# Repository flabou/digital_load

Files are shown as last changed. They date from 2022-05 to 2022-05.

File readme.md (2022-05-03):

# Digital load
This is a digital load circuit, project is WIP.
Intended features are:
- USB type-C connector with USB-2.0 supply (5V 500mA)
- Oled display to show current setting (and maybe other stuff)
- Encoder wheel with push-button to change current value
- Ability to connect several circuit (only one with screen, encoder, and usb supply) which will communicate through I2C and share the load (to reach higher current load)
- Several sense resistors to increase dynamic range.
- Maximum current and voltage are to be determined, current will probably be on the order of 1 to 5 amps max, ~1uA min
- USB serial interface, maybe to control from computer and read measured current points, this would allow to specify curve for the load for instance, if there's a use for it.

# Screenshots

Render of the board (top)

Render of the board (perspective)

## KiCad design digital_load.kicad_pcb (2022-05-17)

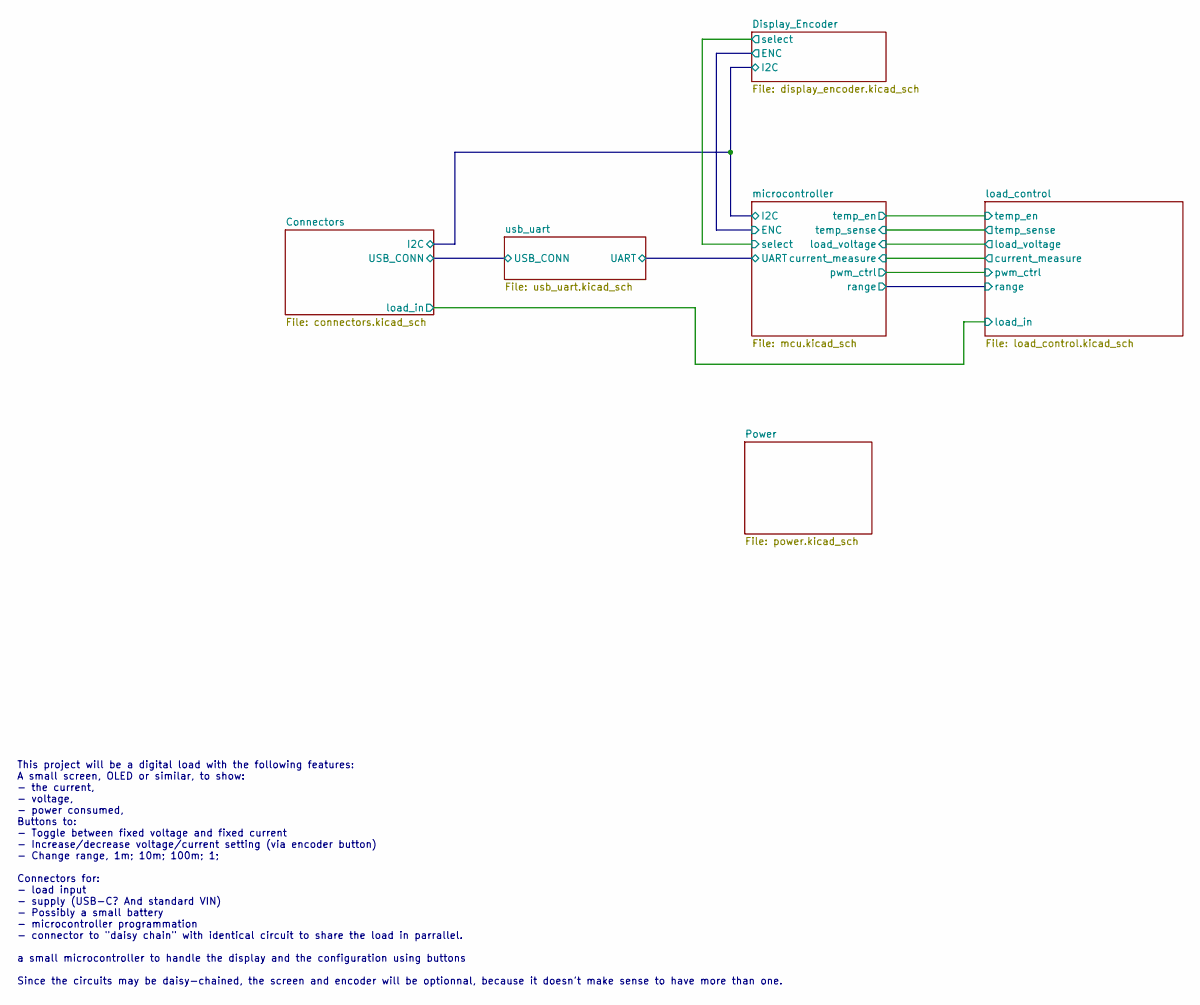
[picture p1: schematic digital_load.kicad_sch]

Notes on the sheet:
This project will be a digital load with the following features: A small screen, OLED or similar, to show: - the current, - voltage, - power consumed, Buttons to: - Toggle between fixed voltage and fixed current - Increase/decrease voltage/current setting (via encoder button) - Change range, 1m; 10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

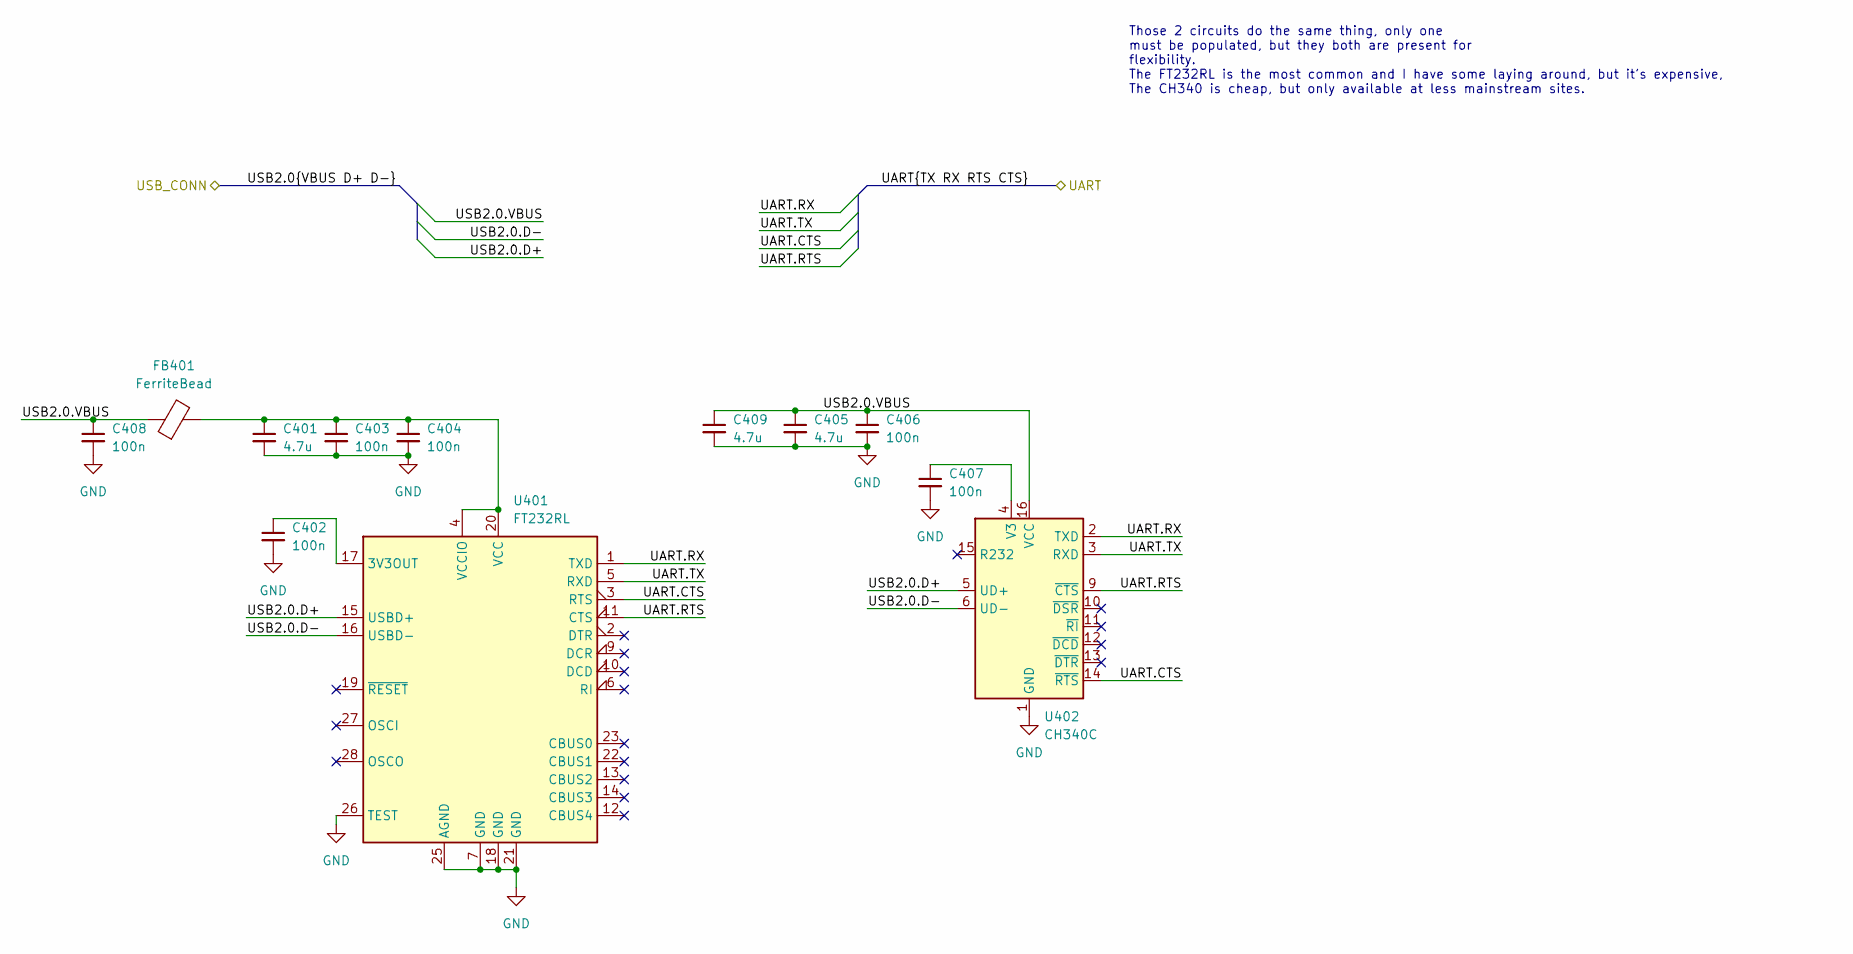
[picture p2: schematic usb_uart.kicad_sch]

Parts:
C401, C405, C409: 4.7u; C_0805_2012Metric; PartNumber Generic
C402, C403, C404, C406, C407, C408: 100n; C_0402_1005Metric; PartNumber Generic
FB401: FerriteBead; L_0805_2012Metric; PartNumber MH2029-400Y
U401: FT232RL; SSOP-28_5.3x10.2mm_P0.65mm; PartNumber FT232RL
U402: CH340C; SOIC-16_3.9x9.9mm_P1.27mm; PartNumber CH340C

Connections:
+5V: C405.1, C406.1, C408.1, C409.1, FB401.1, U402.16 (VCC); also elsewhere on the board
/Connectors/USB2.0.D+: U401.15 (USBD+), U402.5 (UD+); also elsewhere on the board
/Connectors/USB2.0.D-: U401.16 (USBD-), U402.6 (UD-); also elsewhere on the board
/microcontroller/UART.CTS: U401.3 (RTS), U402.14 (~RTS); also elsewhere on the board
/microcontroller/UART.RTS: U401.11 (CTS), U402.9 (~CTS); also elsewhere on the board
/microcontroller/UART.RX: U401.1 (TXD), U402.2 (TXD); also elsewhere on the board
/microcontroller/UART.TX: U401.5 (RXD), U402.3 (RXD); also elsewhere on the board
GND: C401.2, C402.2, C403.2, C404.2, C405.2, C406.2, C407.2, C408.2, C409.2, U401.7 (GND), U401.18 (GND), U401.21 (GND), U401.25 (AGND), U401.26 (TEST), U402.1 (GND); also elsewhere on the board
unnamed: C401.1, C403.1, C404.1, FB401.2, U401.4 (VCCIO), U401.20 (VCC)
unnamed: C402.1, U401.17 (3V3OUT)
unnamed: C407.1, U402.4 (V3)

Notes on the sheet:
Those 2 circuits do the same thing, only one must be populated, but they both are present for flexibility. The FT232RL is the most common and I have some laying around, but it's expensive, The CH340 is cheap, but only available at less mainstream sites.

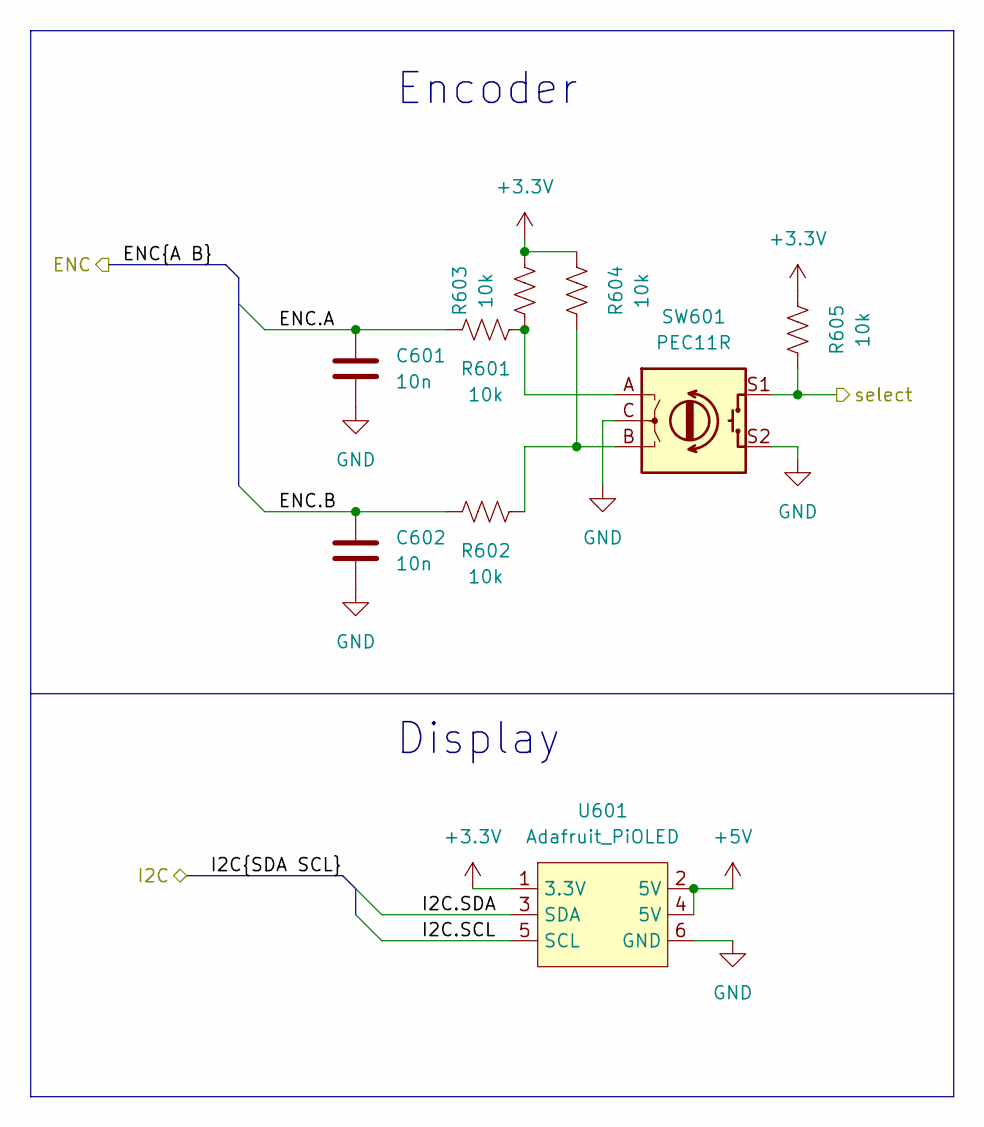
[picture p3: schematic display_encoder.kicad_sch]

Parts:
C601, C602: 10n; C_0805_2012Metric; PartNumber Generic
R601, R602, R603, R604, R605: 10k; R_0805_2012Metric; PartNumber Generic
SW601: PEC11R; RotaryEncoder_Alps_EC12E-Switch_Vertical_H20mm; PartNumber PEC11R-4215F-S0024
U601: Adafruit_PiOLED; PiOLED; PartNumber PiOled

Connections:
+3V3: R603.1, R604.2, R605.2, U601.1 (3.3V); also elsewhere on the board
+5V: U601.2 (5V), U601.4 (5V); also elsewhere on the board
/Connectors/I2C.SCL: U601.5 (SCL); also elsewhere on the board
/Connectors/I2C.SDA: U601.3 (SDA); also elsewhere on the board
/Display_Encoder/ENC.A: C601.2, R601.1; also elsewhere on the board
/Display_Encoder/ENC.B: C602.2, R602.1; also elsewhere on the board
/Display_Encoder/select: R605.1, SW601.S1; also elsewhere on the board
GND: C601.1, C602.1, SW601.C, SW601.S2, U601.6 (GND); also elsewhere on the board
unnamed: R601.2, R603.2, SW601.A
unnamed: R602.2, R604.1, SW601.B

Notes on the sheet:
Encoder
Display

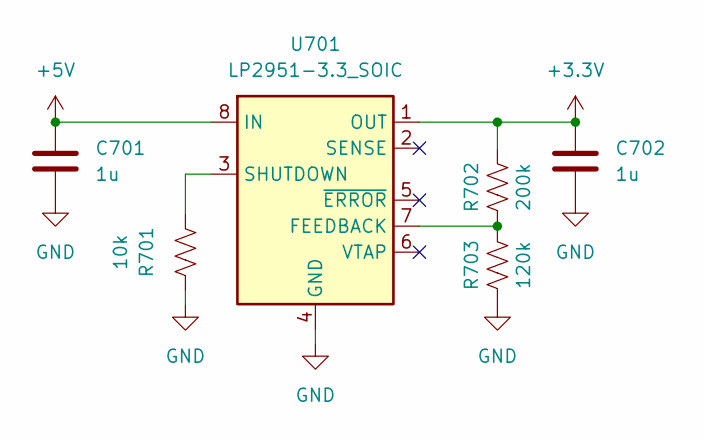
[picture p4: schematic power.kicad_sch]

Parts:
C701, C702: 1u; C_0805_2012Metric; PartNumber Generic
R701: 10k; R_0805_2012Metric; PartNumber Generic
R702: 200k; R_0805_2012Metric; PartNumber Generic
R703: 120k; R_0805_2012Metric; PartNumber Generic
U701: LP2951-3.3_SOIC; SOIC-8_3.9x4.9mm_P1.27mm; PartNumber LP2951-30D

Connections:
+3V3: C702.1, R702.1, U701.1 (OUT); also elsewhere on the board
+5V: C701.1, U701.8 (IN); also elsewhere on the board
GND: C701.2, C702.2, R701.2, R703.2, U701.4 (GND); also elsewhere on the board
unnamed: R701.1, U701.3 (SHUTDOWN)
unnamed: R702.2, R703.1, U701.7 (FEEDBACK)

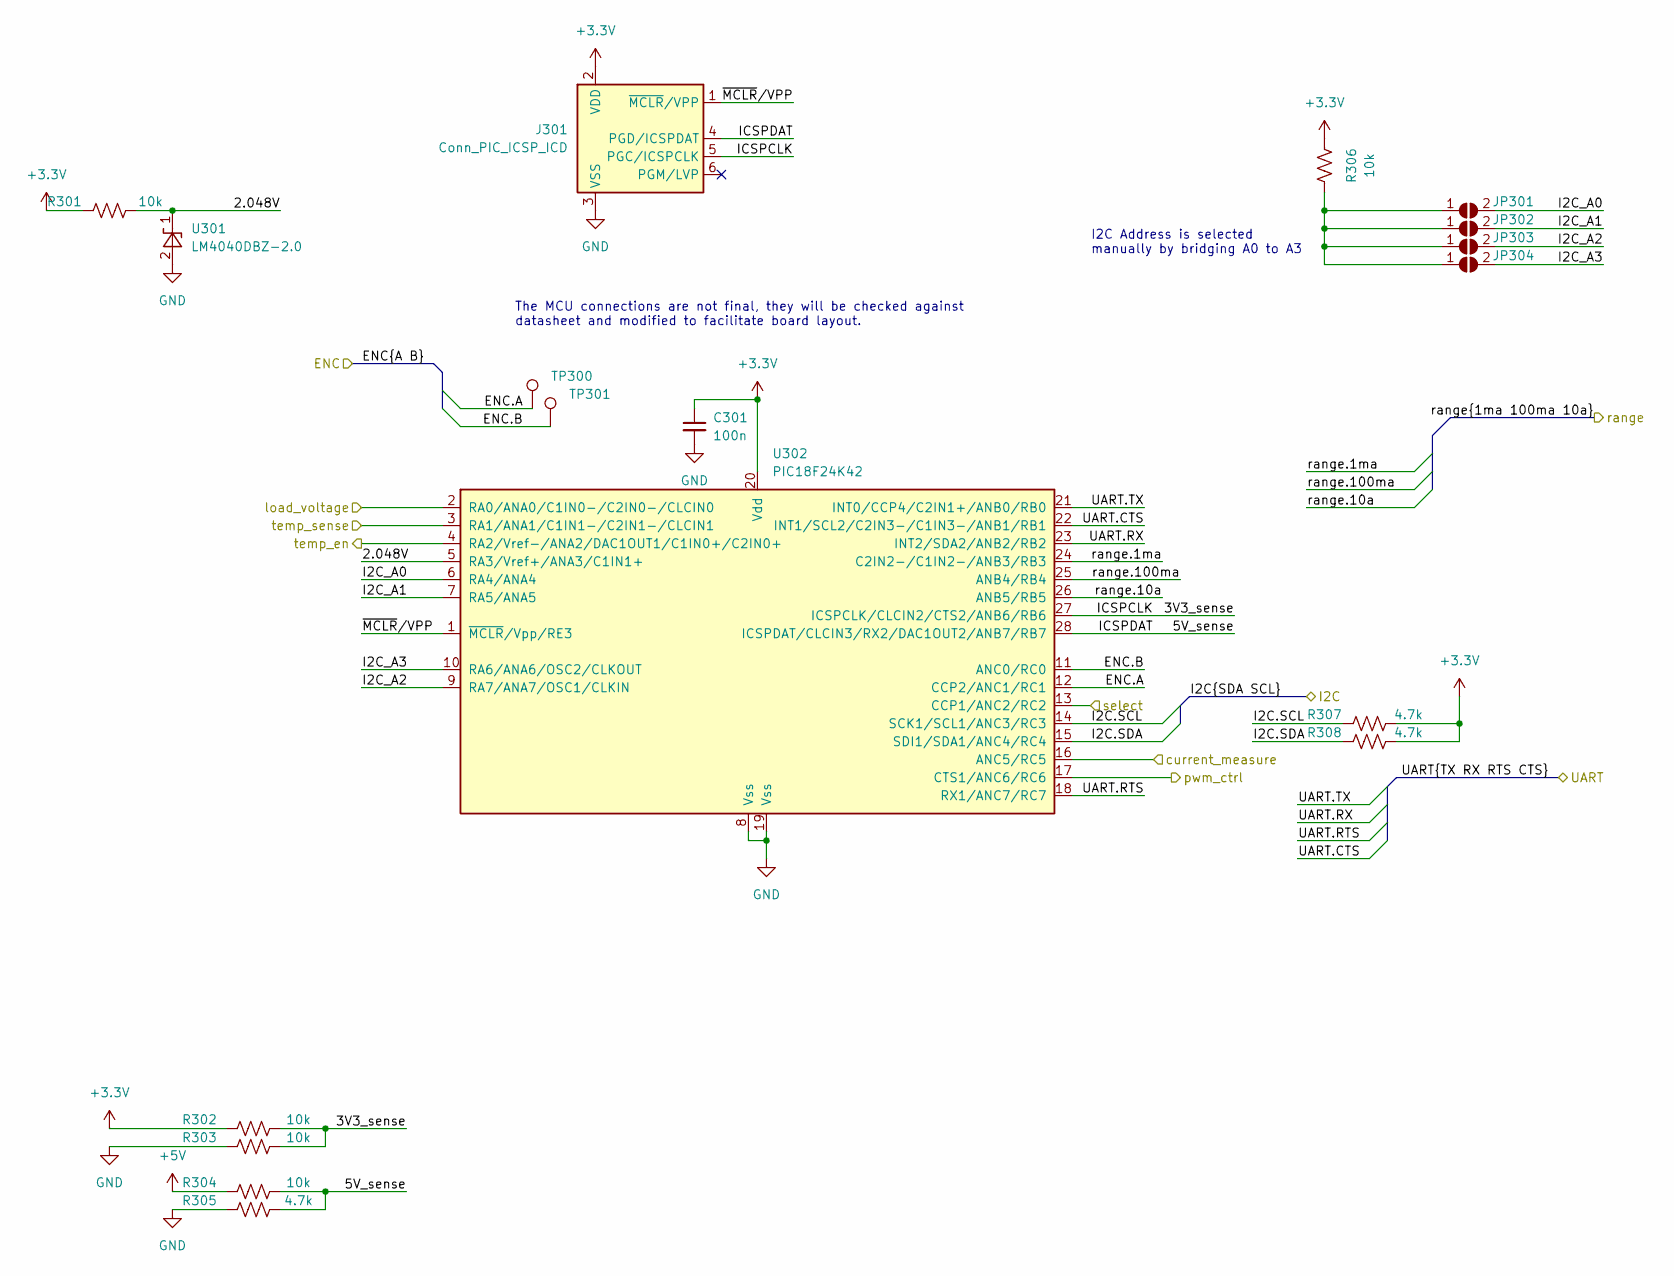
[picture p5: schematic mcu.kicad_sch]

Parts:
C301: 100n; C_0402_1005Metric; PartNumber Generic
J301: Conn_PIC_ICSP_ICD; PinHeader_1x06_P2.54mm_Vertical; PartNumber Generic
JP301, JP302, JP303, JP304: SB; SolderJumper-2_P1.3mm_Open_TrianglePad1.0x1.5mm; PartNumber N.A.
R301, R302, R303, R304, R306: 10k; R_0805_2012Metric; PartNumber Generic
R305, R307, R308: 4.7k; R_0805_2012Metric; PartNumber Generic
TP300, TP301: TestPoint_Pad_D1.0mm; PartNumber N.A.
U301: LM4040DBZ-2.0; SOT-23; PartNumber LM4040C20QDBZT
U302: PIC18F24K42; SSOP-28_5.3x10.2mm_P0.65mm; PartNumber PIC18F24K42

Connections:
+3V3: C301.1, J301.2 (VDD), R301.2, R302.2, R306.2, R307.1, R308.1, U302.20 (Vdd); also elsewhere on the board
+5V: R304.2; also elsewhere on the board
/Connectors/I2C.SCL: R307.2, U302.14 (SCK1/SCL1/ANC3/RC3); also elsewhere on the board
/Connectors/I2C.SDA: R308.2, U302.15 (SDI1/SDA1/ANC4/RC4); also elsewhere on the board
/Display_Encoder/ENC.A: TP300.1, U302.12 (CCP2/ANC1/RC1); also elsewhere on the board
/Display_Encoder/ENC.B: TP301.1, U302.11 (ANC0/RC0); also elsewhere on the board
/Display_Encoder/select: U302.13 (CCP1/ANC2/RC2); also elsewhere on the board
/load_control/current_measure: U302.16 (ANC5/RC5); also elsewhere on the board
/load_control/load_voltage: U302.2 (RA0/ANA0/C1IN0-/C2IN0-/CLCIN0); also elsewhere on the board
/load_control/pwm_ctrl: U302.17 (CTS1/ANC6/RC6); also elsewhere on the board
/load_control/range.1ma: U302.24 (C2IN2-/C1IN2-/ANB3/RB3); also elsewhere on the board
/load_control/range.10a: U302.26 (ANB5/RB5); also elsewhere on the board
/load_control/range.100ma: U302.25 (ANB4/RB4); also elsewhere on the board
/load_control/temp_en: U302.4 (RA2/Vref-/ANA2/DAC1OUT1/C1IN0+/C2IN0+); also elsewhere on the board
/load_control/temp_sense: U302.3 (RA1/ANA1/C1IN1-/C2IN1-/CLCIN1); also elsewhere on the board
/microcontroller/2.048V: R301.1, U301.1 (K), U302.5 (RA3/Vref+/ANA3/C1IN1+)
/microcontroller/3V3_sense: J301.5 (PGC/ICSPCLK), R302.1, R303.2, U302.27 (ICSPCLK/CLCIN2/CTS2/ANB6/RB6)
/microcontroller/5V_sense: J301.4 (PGD/ICSPDAT), R304.1, R305.2, U302.28 (ICSPDAT/CLCIN3/RX2/DAC1OUT2/ANB7/RB7)
/microcontroller/I2C_A0: JP301.2 (B), U302.6 (RA4/ANA4)
/microcontroller/I2C_A1: JP302.2 (B), U302.7 (RA5/ANA5)
/microcontroller/I2C_A2: JP303.2 (B), U302.9 (RA7/ANA7/OSC1/CLKIN)
/microcontroller/I2C_A3: JP304.2 (B), U302.10 (RA6/ANA6/OSC2/CLKOUT)
/microcontroller/UART.CTS: U302.22 (INT1/SCL2/C2IN3-/C1IN3-/ANB1/RB1); also elsewhere on the board
/microcontroller/UART.RTS: U302.18 (RX1/ANC7/RC7); also elsewhere on the board
/microcontroller/UART.RX: U302.23 (INT2/SDA2/ANB2/RB2); also elsewhere on the board
/microcontroller/UART.TX: U302.21 (INT0/CCP4/C2IN1+/ANB0/RB0); also elsewhere on the board
/microcontroller/~MCLR/VPP: J301.1 (~MCLR/VPP), U302.1 (~MCLR/Vpp/RE3)
GND: C301.2, J301.3 (VSS), R303.1, R305.1, U301.2 (A), U302.8 (Vss), U302.19 (Vss); also elsewhere on the board
unnamed: JP301.1 (A), JP302.1 (A), JP303.1 (A), JP304.1 (A), R306.1

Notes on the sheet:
I2C Address is selected manually by bridging A0 to A3
The MCU connections are not final, they will be checked against datasheet and modified to facilitate board layout.

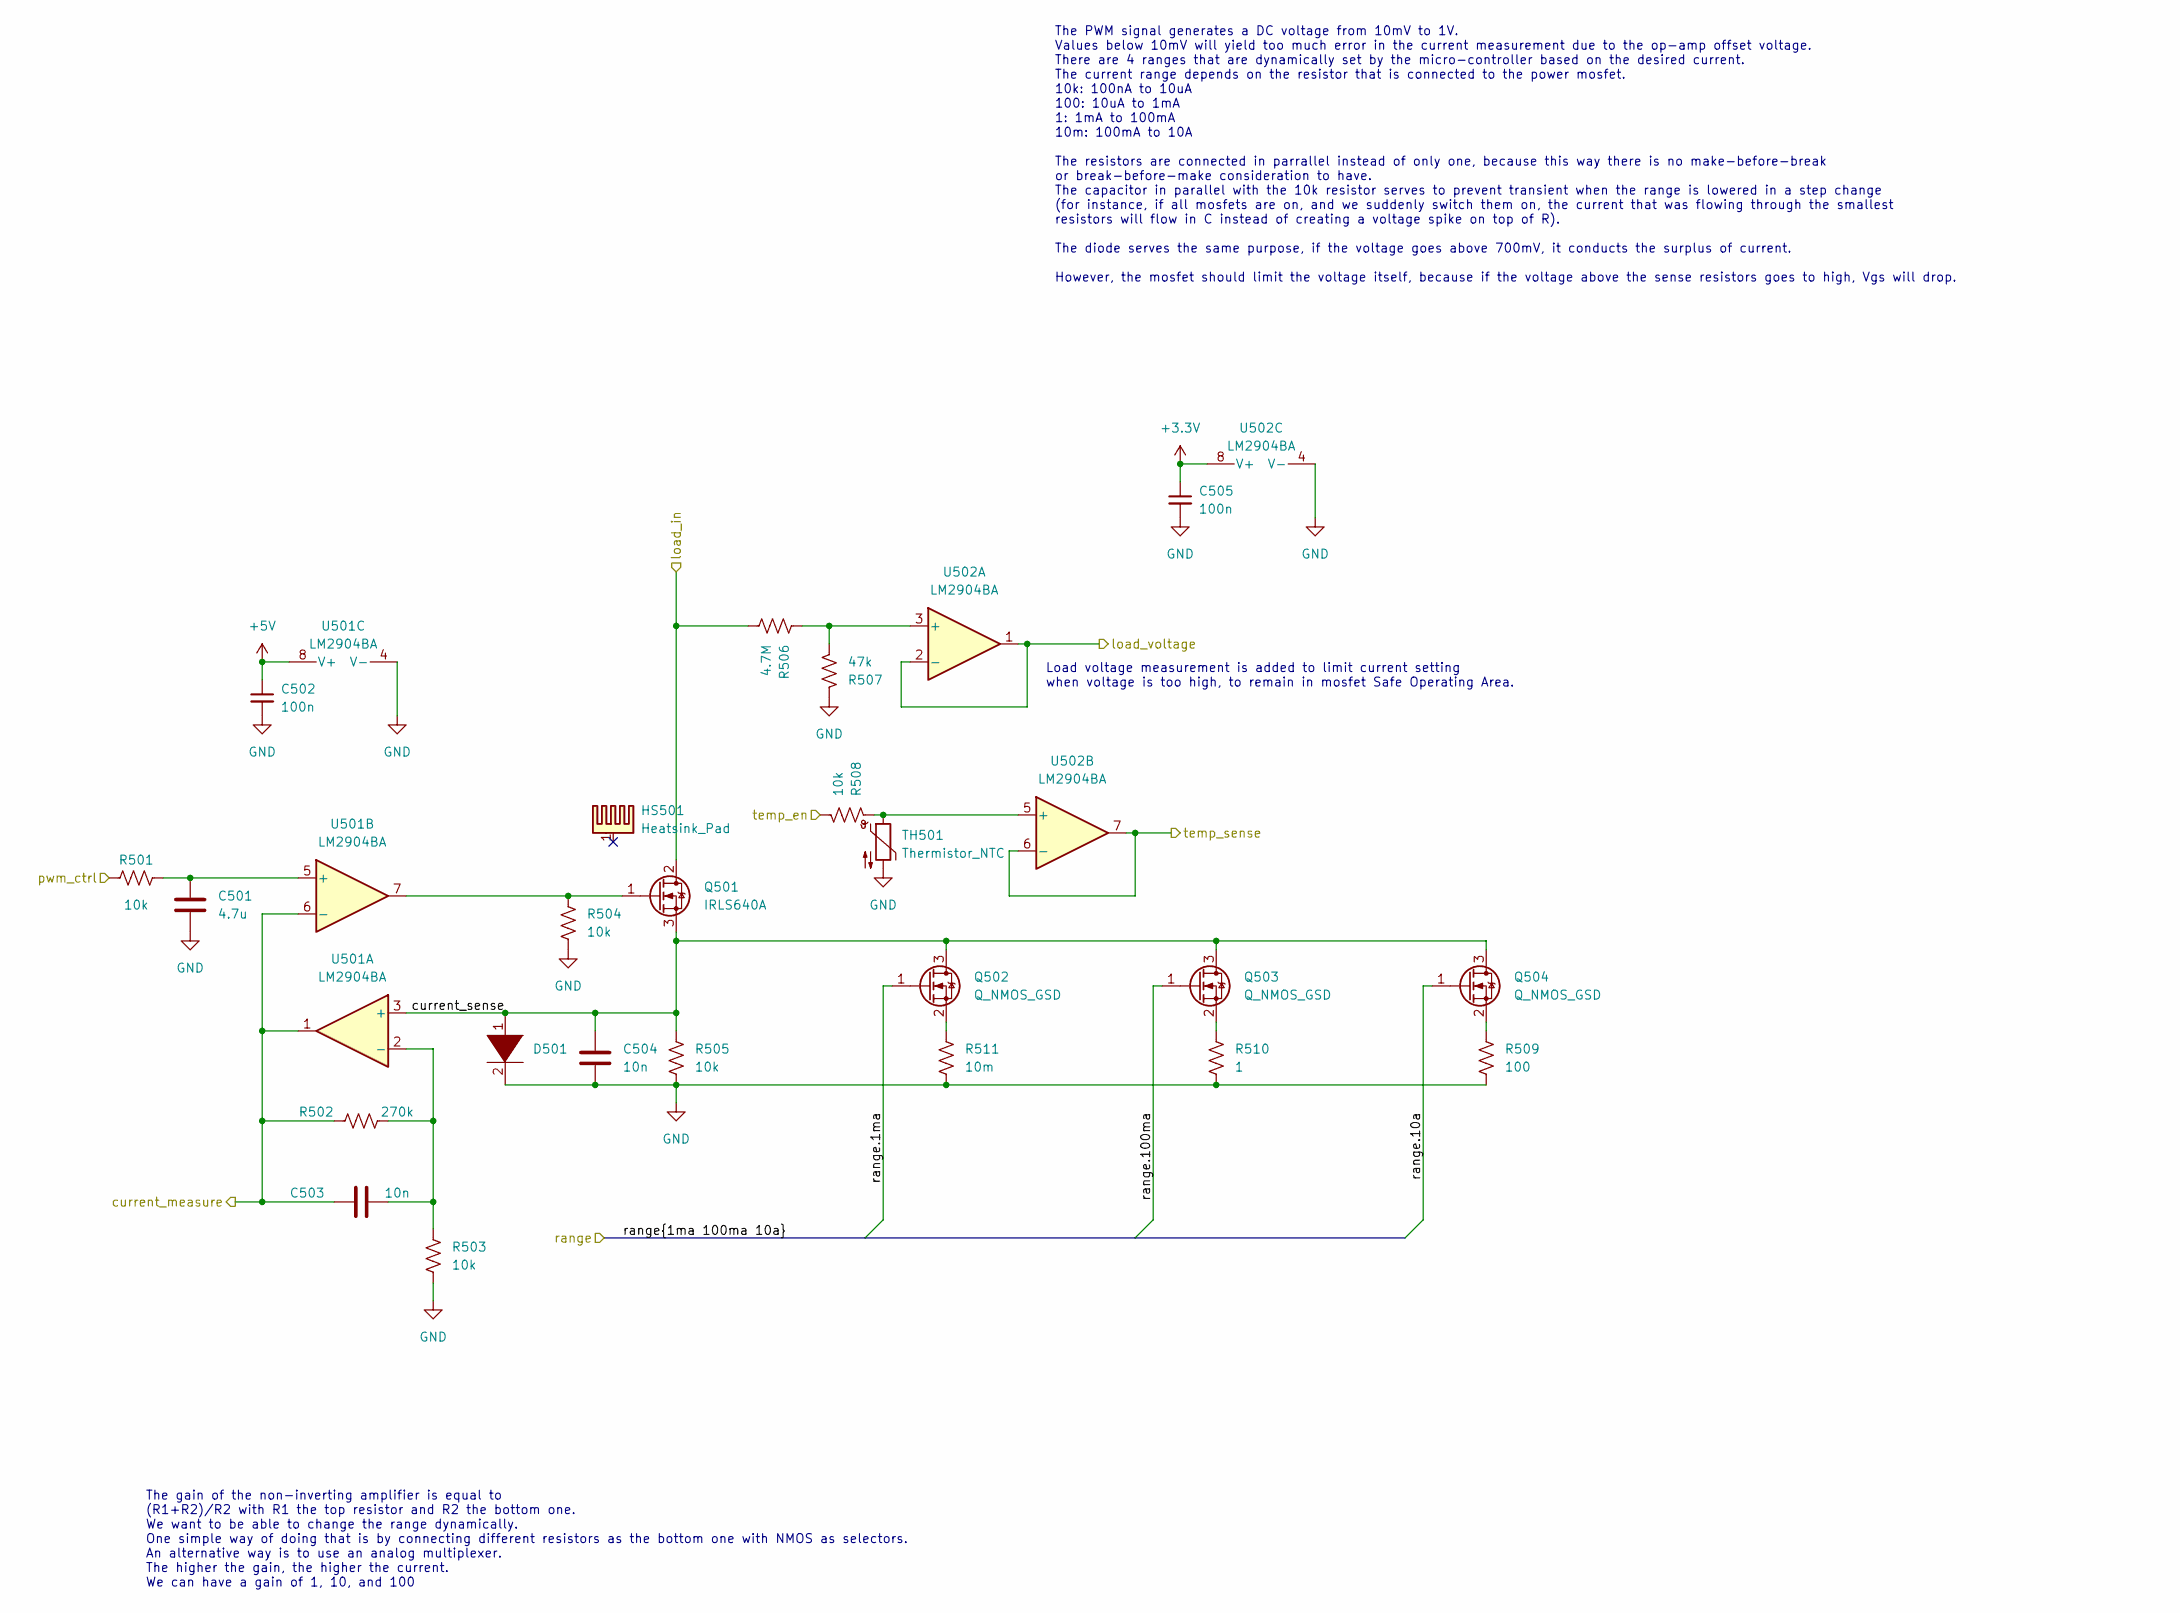
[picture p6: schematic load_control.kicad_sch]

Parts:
C501: 4.7u; C_0805_2012Metric; PartNumber Generic
C502, C505: 100n; C_0402_1005Metric; PartNumber Generic
C503, C504: 10n; C_0805_2012Metric; PartNumber Generic
D501: DIODE; D_SOD-323; PartNumber SD101AWS-TP
HS501: Heatsink_Pad; Heatsink_ASSMANN_WSW_V6560W; PartNumber V6560W
Q501: IRLS640A; TO-220-3_Vertical; PartNumber IRLS640A
Q502, Q503, Q504: Q_NMOS_GSD; SOT-23; PartNumber PJA3404_R1_00001
R501, R503, R504, R505, R508: 10k; R_0805_2012Metric; PartNumber Generic
R502: 270k; R_0805_2012Metric; PartNumber Generic
R506: 4.7M; R_0805_2012Metric; PartNumber Generic
R507: 47k; R_0805_2012Metric; PartNumber Generic
R509: 100; R_0805_2012Metric; PartNumber Generic
R510: 1; R_0805_2012Metric; PartNumber Generic
R511: 10m; R_0805_2012Metric; PartNumber Generic
TH501: Thermistor_NTC; R_0402_1005Metric; PartNumber NTCG103JF103FT1
U501, U502: LM2904BA; TSSOP-8_4.4x3mm_P0.65mm; PartNumber LM2904BAIPWR

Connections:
+3V3: C505.1, U502.8 (V+); also elsewhere on the board
+5V: C502.1, U501.8 (V+); also elsewhere on the board
/Connectors/load_in: Q501.2 (D), R506.1; also elsewhere on the board
/load_control/current_measure: C503.2, R502.2, U501.1, U501.6 (-); also elsewhere on the board
/load_control/current_sense: C504.2, D501.1 (K), Q501.3 (S), Q502.3 (D), Q503.3 (D), Q504.3 (D), R505.2, U501.3 (+)
/load_control/load_voltage: U502.1, U502.2 (-); also elsewhere on the board
/load_control/pwm_ctrl: R501.1; also elsewhere on the board
/load_control/range.1ma: Q502.1 (G); also elsewhere on the board
/load_control/range.10a: Q504.1 (G); also elsewhere on the board
/load_control/range.100ma: Q503.1 (G); also elsewhere on the board
/load_control/temp_en: R508.1; also elsewhere on the board
/load_control/temp_sense: U502.6 (-), U502.7; also elsewhere on the board
GND: C501.2, C502.2, C504.1, C505.2, D501.2 (A), R503.2, R504.1, R505.1, R507.2, R509.1, R510.1, R511.1, TH501.2, U501.4 (V-), U502.4 (V-); also elsewhere on the board
unnamed: C501.1, R501.2, U501.5 (+)
unnamed: C503.1, R502.1, R503.1, U501.2 (-)
unnamed: Q501.1 (G), R504.2, U501.7
unnamed: Q502.2 (S), R511.2
unnamed: Q503.2 (S), R510.2
unnamed: Q504.2 (S), R509.2
unnamed: R506.2, R507.1, U502.3 (+)
unnamed: R508.2, TH501.1, U502.5 (+)

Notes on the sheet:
Load voltage measurement is added to limit current setting when voltage is too high, to remain in mosfet Safe Operating Area.
The gain of the non-inverting amplifier is equal to (R1+R2)/R2 with R1 the top resistor and R2 the bottom one. We want to be able to change the range dynamically. One simple way of doing that is by connecting different resistors as the bottom one with NMOS as selectors. An alternative way is to use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
The PWM signal generates a DC voltage from 10mV to 1V. Values below 10mV will yield too much error in the current measurement due to the op-amp offset voltage. There are 4 ranges that are dynamically set by the micro-controller based on the desired current. The current range depends on the resistor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

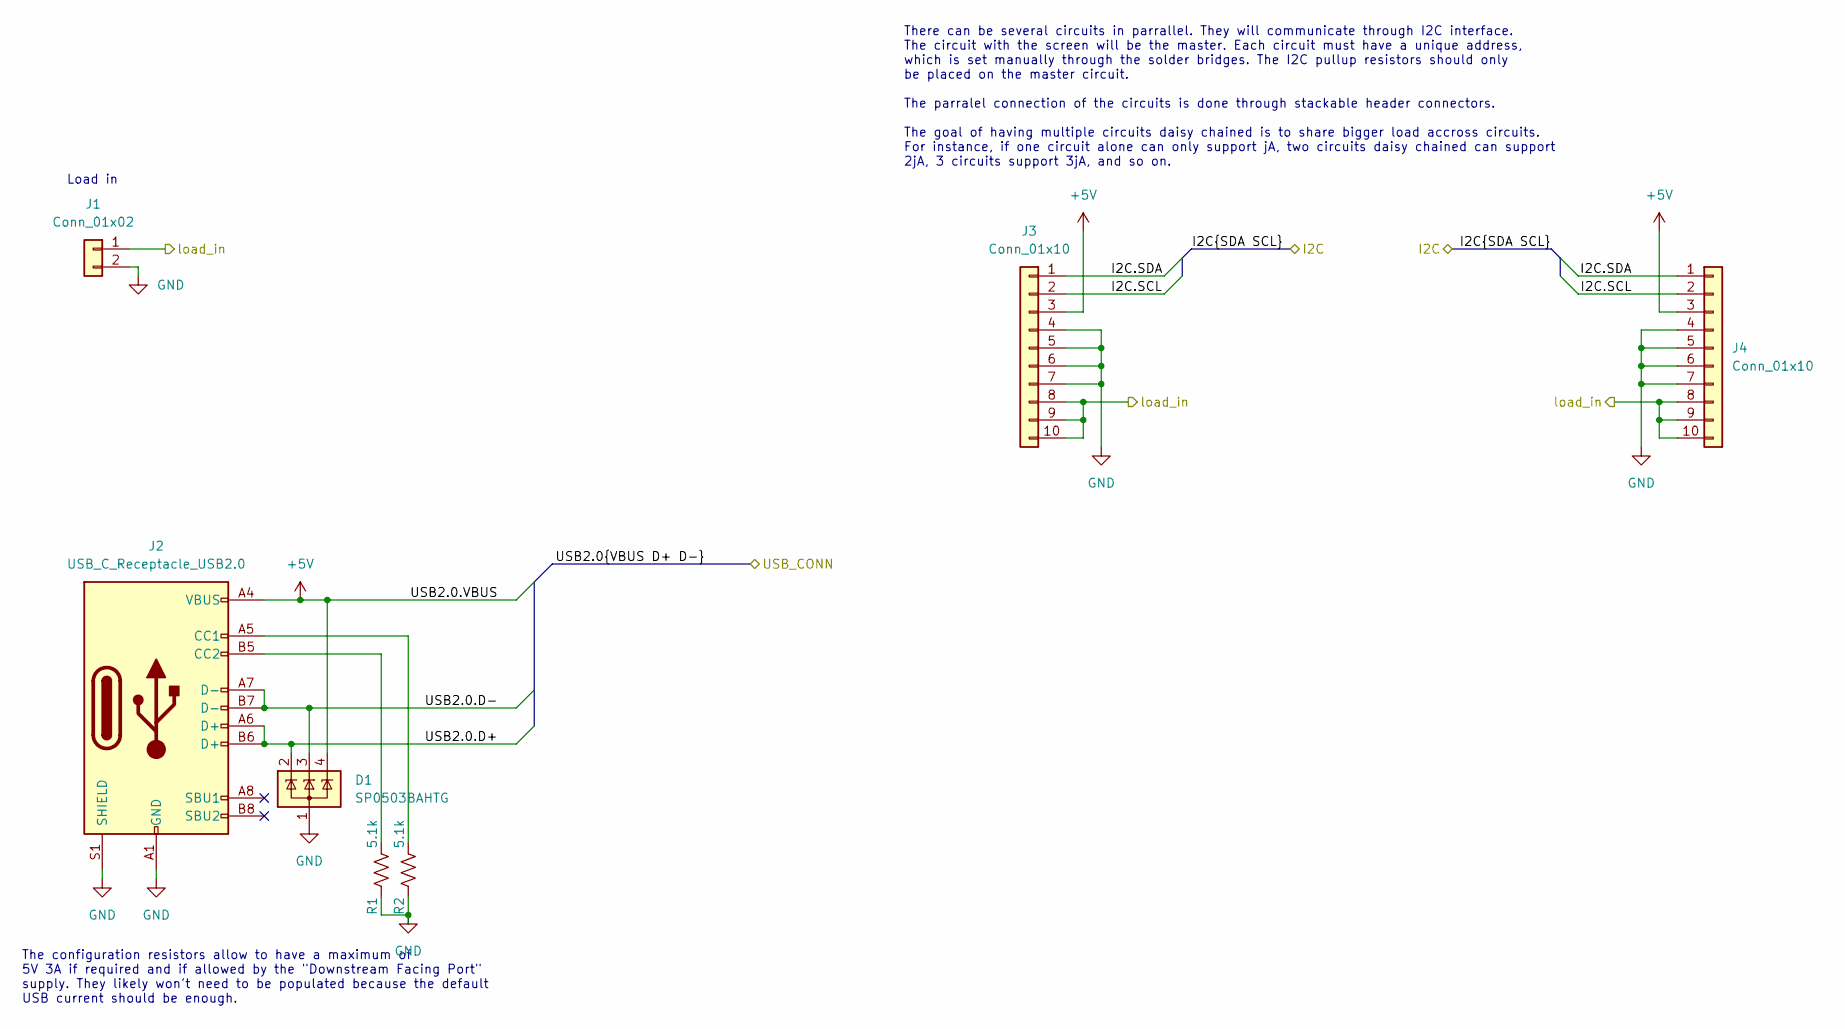
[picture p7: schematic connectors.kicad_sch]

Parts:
D1: SP0503BAHTG; SOT-143; PartNumber SP0503BAHTG
J1: Conn_01x02; PinHeader_1x02_P2.54mm_Horizontal; PartNumber Generic
J2: USB_C_Receptacle_USB2.0; USB_C_Receptacle_GCT_USB4085; PartNumber USB4085
J3, J4: Conn_01x10; PinSocket_1x10_P2.54mm_Vertical; PartNumber Generic
R1, R2: 5.1k; R_0805_2012Metric; PartNumber Generic

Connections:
+5V: D1.4 (K), J2.A4 (VBUS), J2.A9 (VBUS), J2.B4 (VBUS), J2.B9 (VBUS), J3.3, J4.3; also elsewhere on the board
/Connectors/I2C.SCL: J3.2, J4.2; also elsewhere on the board
/Connectors/I2C.SDA: J3.1, J4.1; also elsewhere on the board
/Connectors/USB2.0.D+: D1.2 (K), J2.A6 (D+), J2.B6 (D+); also elsewhere on the board
/Connectors/USB2.0.D-: D1.3 (K), J2.A7 (D-), J2.B7 (D-); also elsewhere on the board
/Connectors/load_in: J1.1, J3.8, J3.9, J3.10, J4.8, J4.9, J4.10; also elsewhere on the board
GND: D1.1 (A), J1.2, J2.A1 (GND), J2.A12 (GND), J2.B1 (GND), J2.B12 (GND), J2.S1 (SHIELD), J3.4, J3.5, J3.6, J3.7, J4.4, J4.5, J4.6, J4.7, R1.1, R2.1; also elsewhere on the board
unnamed: J2.A5 (CC1), R2.2
unnamed: J2.B5 (CC2), R1.2

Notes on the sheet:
The configuration resistors allow to have a maximum of 5V 3A if required and if allowed by the "Downstream Facing Port" supply. They likely won't need to be populated because the default USB current should be enough.
There can be several circuits in parrallel. They will communicate through I2C interface. The circuit with the screen will be the master. Each circuit must have a unique address, which is set manually through the solder bridges. The I2C pullup resistors should only be placed on the master circuit. T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
Load in

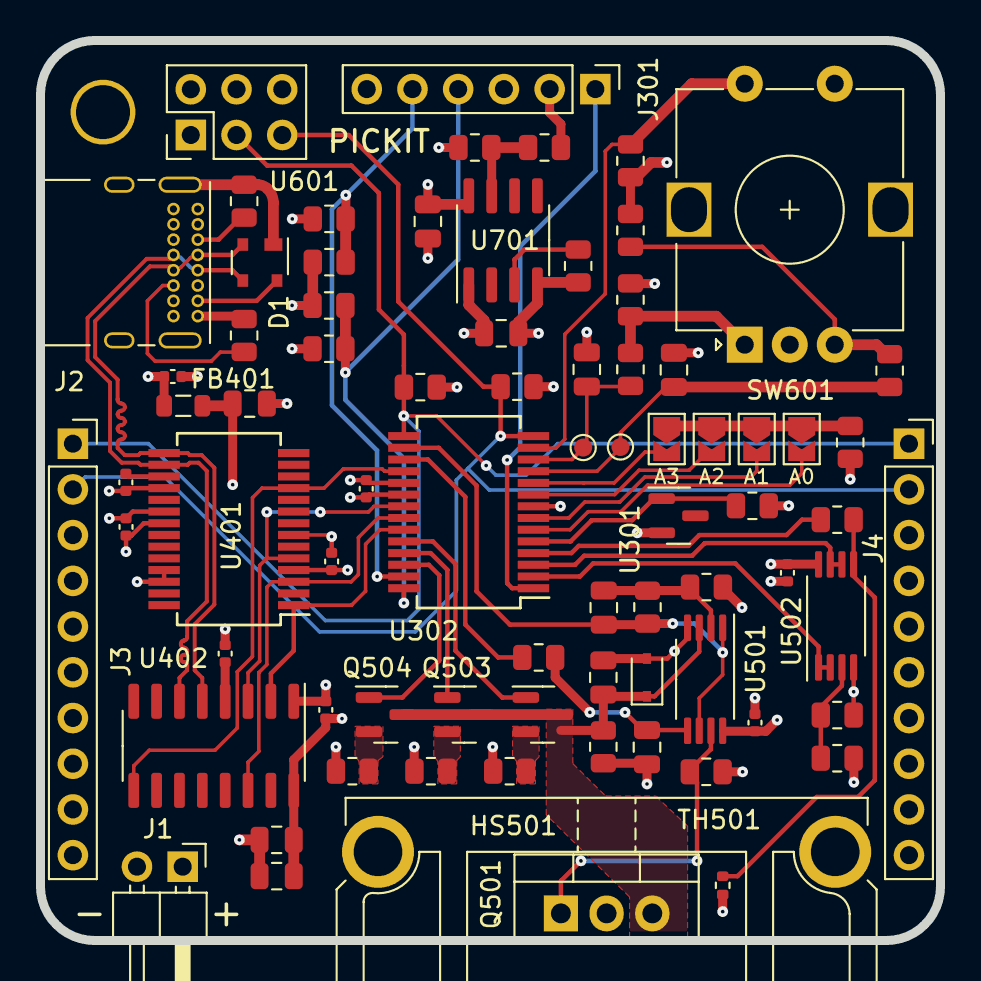
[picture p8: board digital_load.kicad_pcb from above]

Board: 4 copper layers, 50.0 x 50.0 mm, 77 parts (0 on the bottom side), 50 nets.

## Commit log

2022-04-09 Replace UART{R,L} with I2C
    [connectors.kicad_sch, digital_load.kicad_sch, mcu.kicad_sch]
2022-04-09 Add voltage reference and voltage regulator
    [connectors.kicad_sch, digital_load.kicad_sch, display_encoder.kicad_sch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]
2022-04-11 Add uart usb controller
    [connectors.kicad_sch, digital_load.kicad_pcb, digital_load.kicad_sch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]
2022-04-12 Fix lots of small things
    [connectors.kicad_sch, digital_load.kicad_pcb, digital_load.kicad_sch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]
2022-04-12 Arrange components of subcircuits
    [digital_load.kicad_pcb, digital_load.kicad_sch, display_encoder.kicad_sch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]
2022-04-17 WIP PCB Routing + Add load voltage measure
    [digital_load.kicad_pcb, digital_load.kicad_sch, load_control.kicad_sch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]
2022-04-18 WIP PCB Routing
    [connectors.kicad_sch, digital_load.kicad_pcb, digital_load.kicad_sch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]
2022-04-23 Add heatsink, among other things
    [connectors.kicad_sch, digital_load.kicad_pcb, digital_load.kicad_sch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]
2022-04-24 WIP routing
    [connectors.kicad_sch, digital_load.kicad_pcb, digital_load.kicad_sch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]
2022-04-26 Routing almost complete
    [digital_load.kicad_pcb]
2022-04-29 Fix and tune differential pair and zones
    [connectors.kicad_sch, digital_load.kicad_pcb, display_encoder.kicad_sch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]
2022-04-30 Add partnumbers
    [connectors.kicad_sch, digital_load.kicad_pcb, digital_load.kicad_sch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]
2022-04-30 Add bom generator based on kicad examples
2022-05-01 Fix missing footprints in schematic
    [connectors.kicad_sch, digital_load.kicad_pcb, digital_load.kicad_sch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]
2022-05-01 Add feedback resistors for regulator
    [digital_load.kicad_pcb, digital_load.kicad_sch, mcu.kicad_sch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]
2022-05-02 Change some partnumbers in preparation for the order
    [digital_load.kicad_pcb, digital_load.kicad_sch, load_control.kicad_sch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]
2022-05-02 Unclutter silk screen
    [digital_load.kicad_pcb]
2022-05-03 Reduce trace resistance of 10mOhm channel
    [connectors.kicad_sch, digital_load.kicad_pcb, display_encoder.kicad_sch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]
2022-05-03 Add round-tracks edition of PCB
    [digital_load-rounded.kicad_pcb]
2022-05-03 Add interractive bom
2022-05-17 Generate interactive bom for main and peripheral variants
    [connectors.kicad_sch, digital_load.kicad_pcb, digital_load.kicad_sch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]
